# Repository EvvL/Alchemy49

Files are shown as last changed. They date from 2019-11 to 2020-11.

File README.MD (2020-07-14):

<p align="center">
   
  <br>
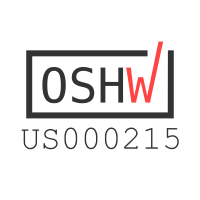
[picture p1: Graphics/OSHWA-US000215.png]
  
</p>

**Status:** Ordering final prototype

## Introduction

The Alchemy49 is a replacement pcb for the Magicforce 49 supporting south facing Switches, LEDs, PCB mounted stabilizers
and QMK. It's built around the SparkFun Pro Micro and designed to be easy to put together and solder using only one
surface mount component.

## BOM (Bill of Materials)

- 1x Promicro (or Compatible)
- 1x Micro USB Cable
- 1x XM7D-0512 MiniB (LCSC: C46398)
- 1x 6mm THT SPST Button
- 49x 1N4148 (LCSC: C14538)

If using LEDs:

- 49x 330 1/6w (LCSC: C119858)
- 49x 1.8mm LED (LCSC: C268275)
- 1x AO3402 (LCSC: C351406)
- 1x 100 1/6w (LCSC: C119846)
- 1x 10k 1/6w (LCSC: C119894)

## Layout

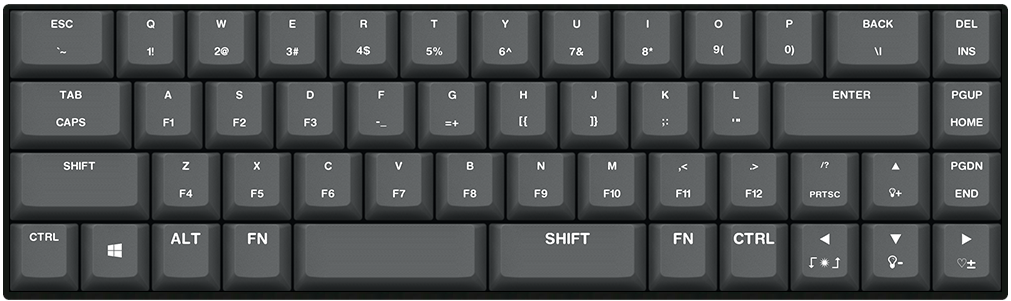
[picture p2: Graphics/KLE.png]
KLE Layout Render


Layout Render by [KLE-Render](http://kle-render.herokuapp.com/)

Click [this link](http://www.keyboard-layout-editor.com/#/gists/9abd5a1e1122fe68672f75864f8e92a3) for the KLE layout

## Firmware

For now QMK is currently supported via [KBFirmware.com](https://kbfirmware.com/). Just upload the included
[Configuration/kbfirmware.json](https://github.com/EvvL/Alchemy49/raw/master/Configuration/kbfirmware.json) into
the site, tweak the layout to your liking and compile. The resulting hex file should be flashable using
[AVRDUDESS](https://github.com/zkemble/AVRDUDESS) or [AVRDUDE](http://www.nongnu.org/avrdude/).

If you don't want to adjust anything you can use the [included prebuilt hex file](https://github.com/EvvL/Alchemy49/raw/master/Configuration/alchemy49.hex)
with all the same configuration as the stock MagicForce49 layout.

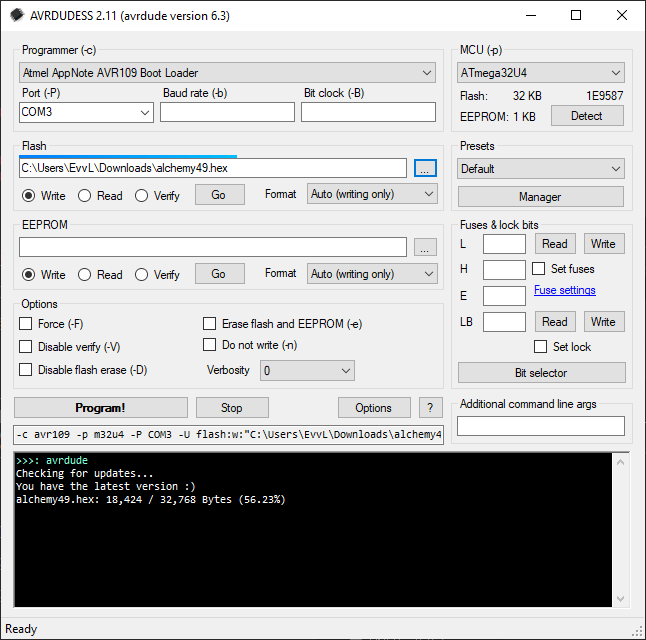
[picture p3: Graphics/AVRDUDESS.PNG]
AVRDUDESS Settings


## Renders

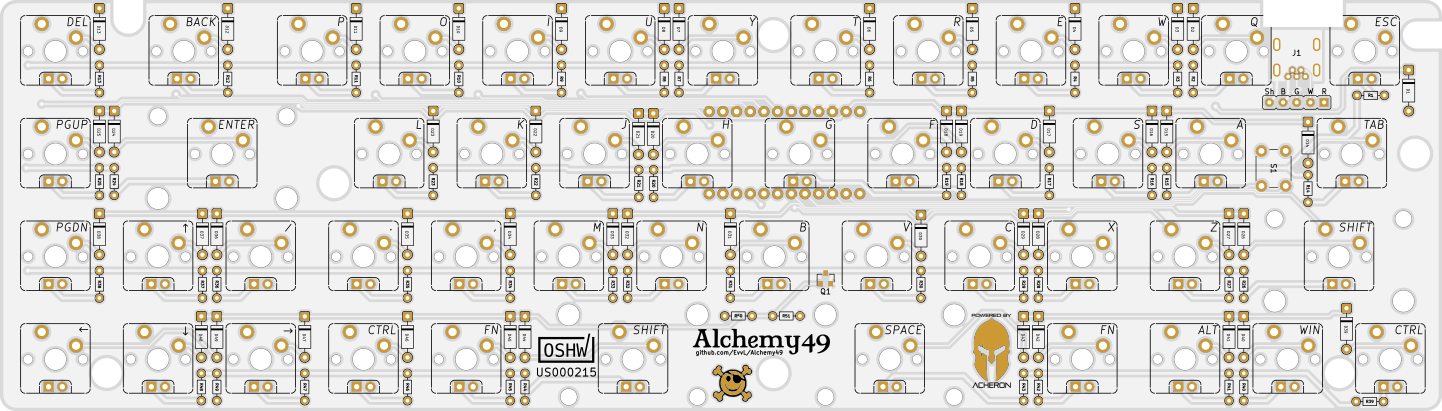
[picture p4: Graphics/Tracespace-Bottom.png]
Tracespace Render (Bottom)


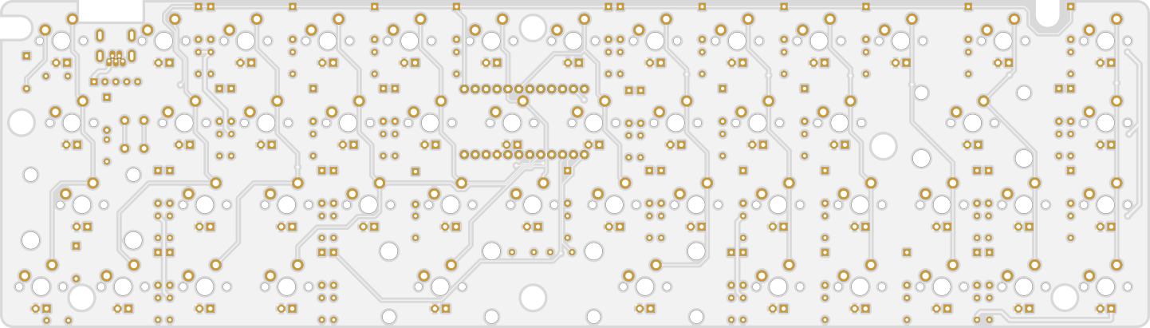
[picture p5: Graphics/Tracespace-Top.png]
Tracespace Render (Top)


PCB Renders by [Tracespace](https://tracespace.io/view/)

## Copyright and Licensing

This project is licensed under the [Acheron Open-Source Hardware License V1.2](https://github.com/EvvL/Alchemy49/blob/master/LICENSE.md)

OSHWA Certification: [US000215](https://certification.oshwa.org/us000215.html)

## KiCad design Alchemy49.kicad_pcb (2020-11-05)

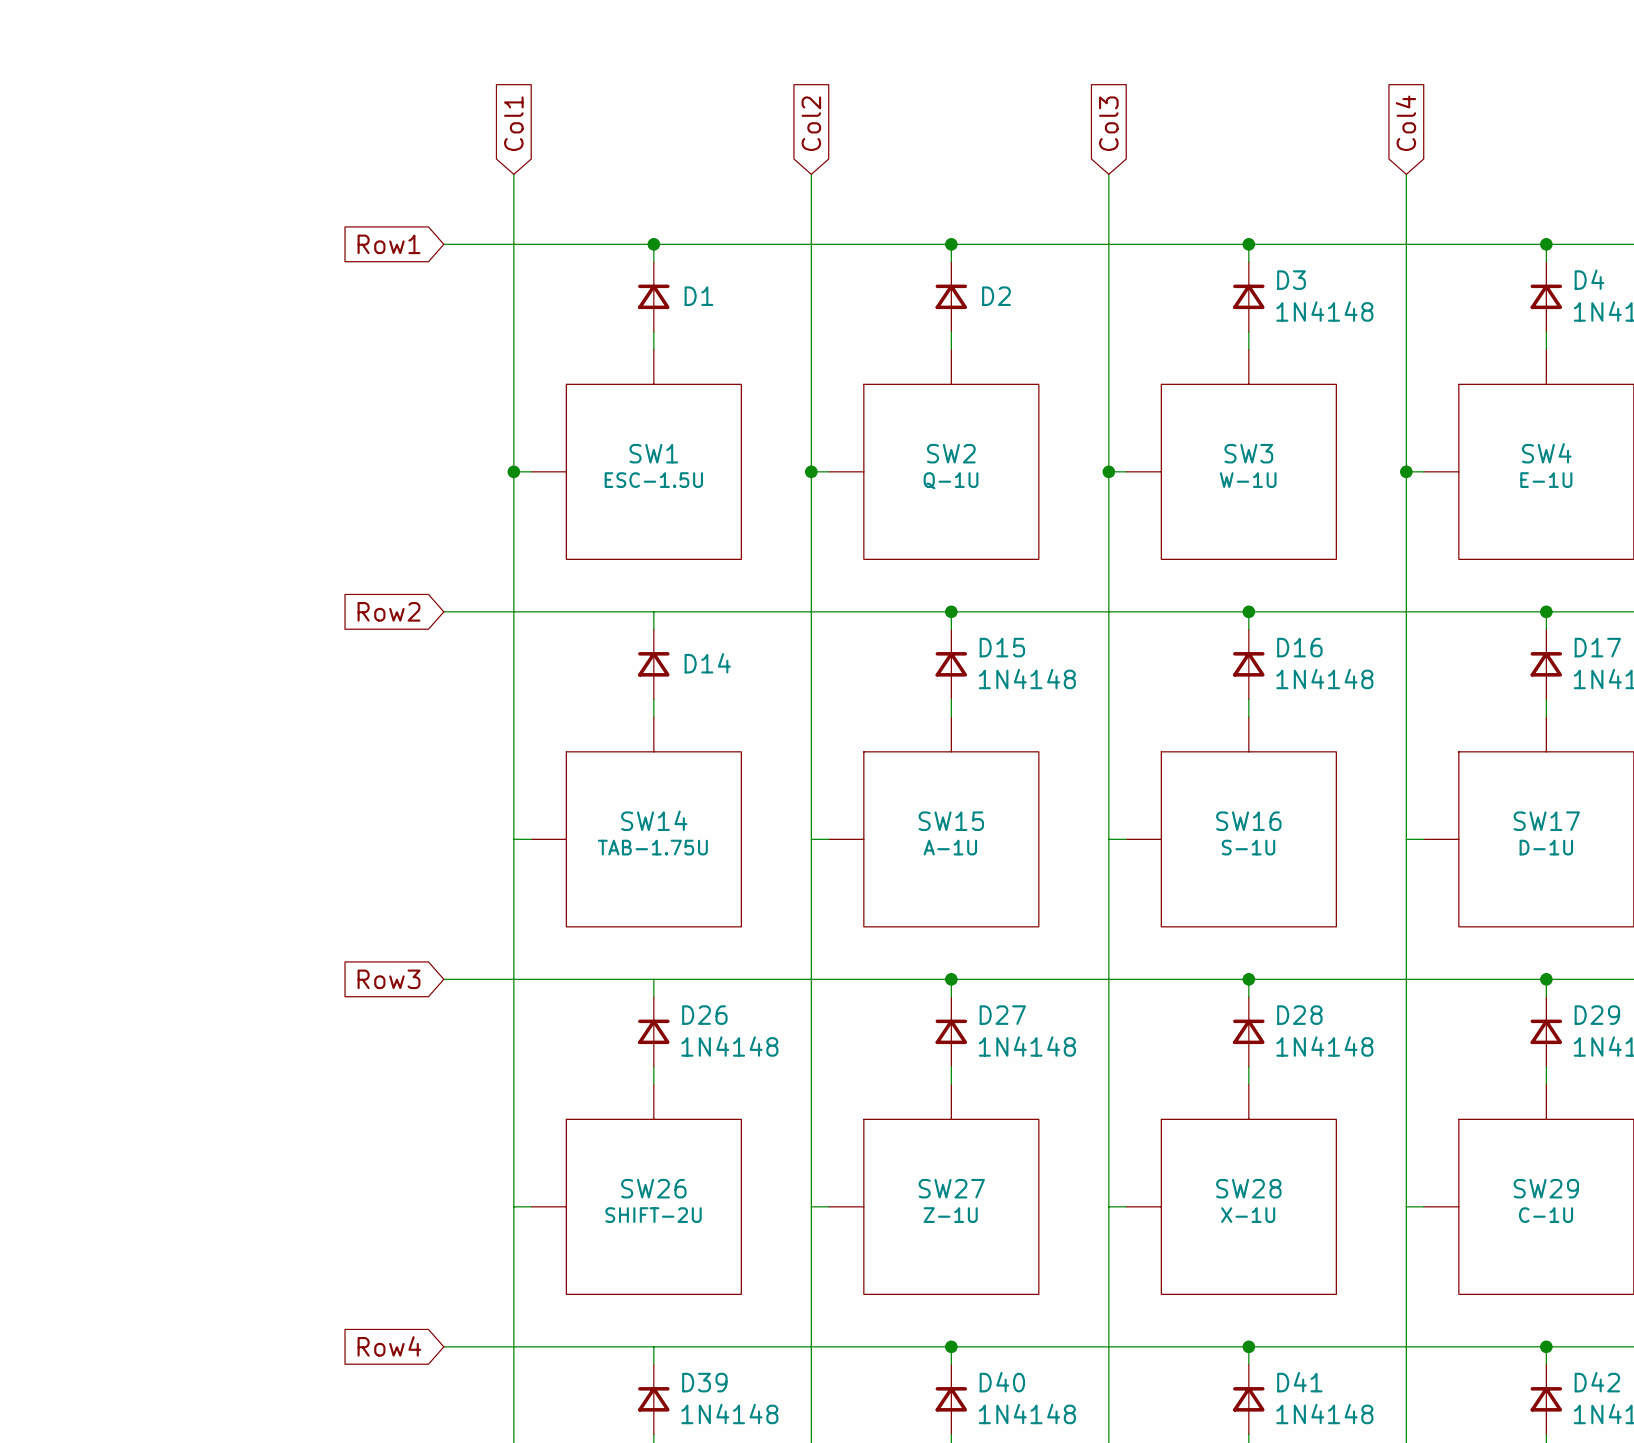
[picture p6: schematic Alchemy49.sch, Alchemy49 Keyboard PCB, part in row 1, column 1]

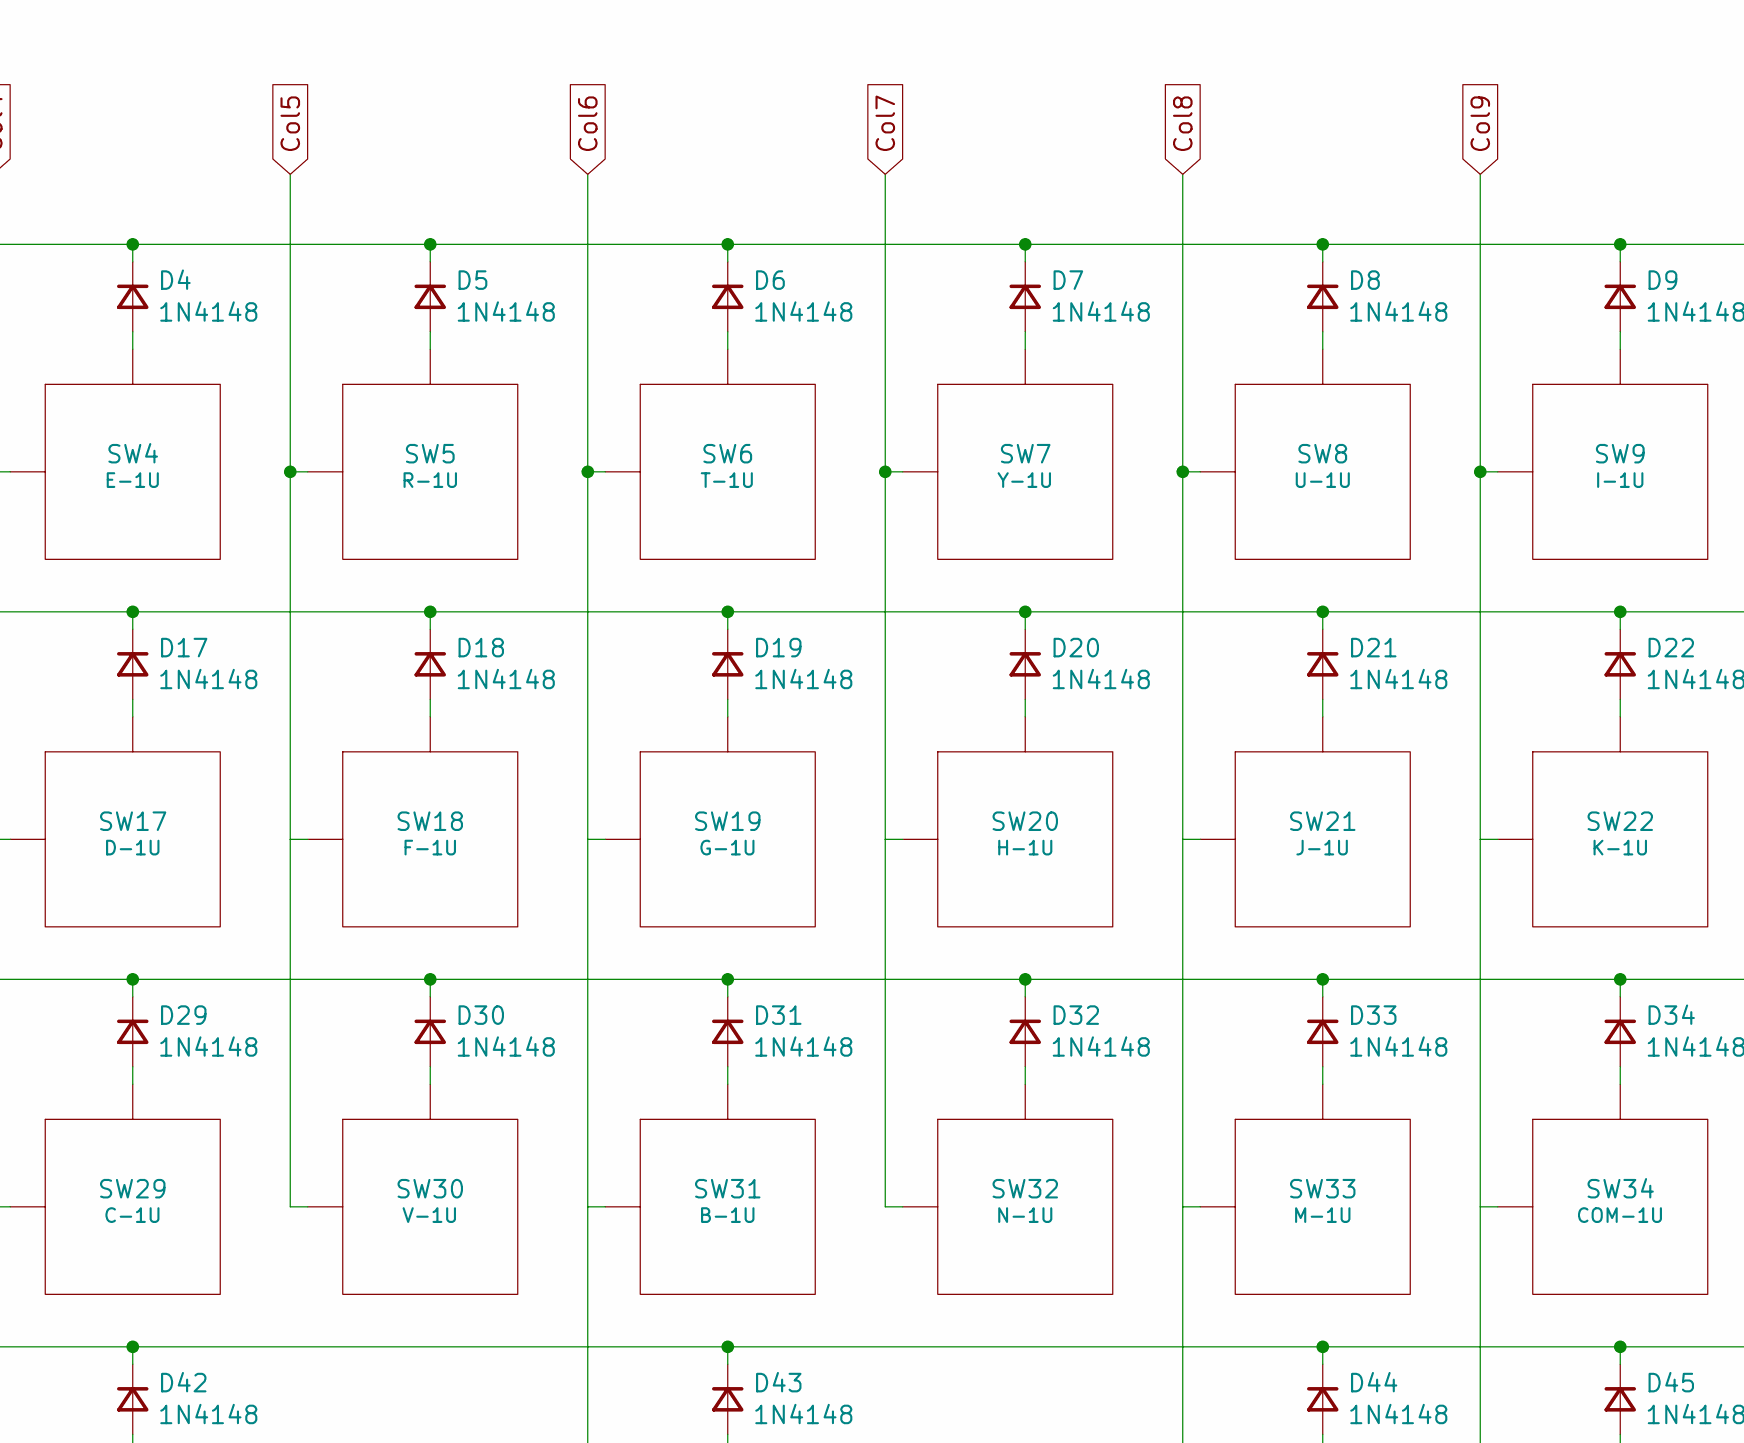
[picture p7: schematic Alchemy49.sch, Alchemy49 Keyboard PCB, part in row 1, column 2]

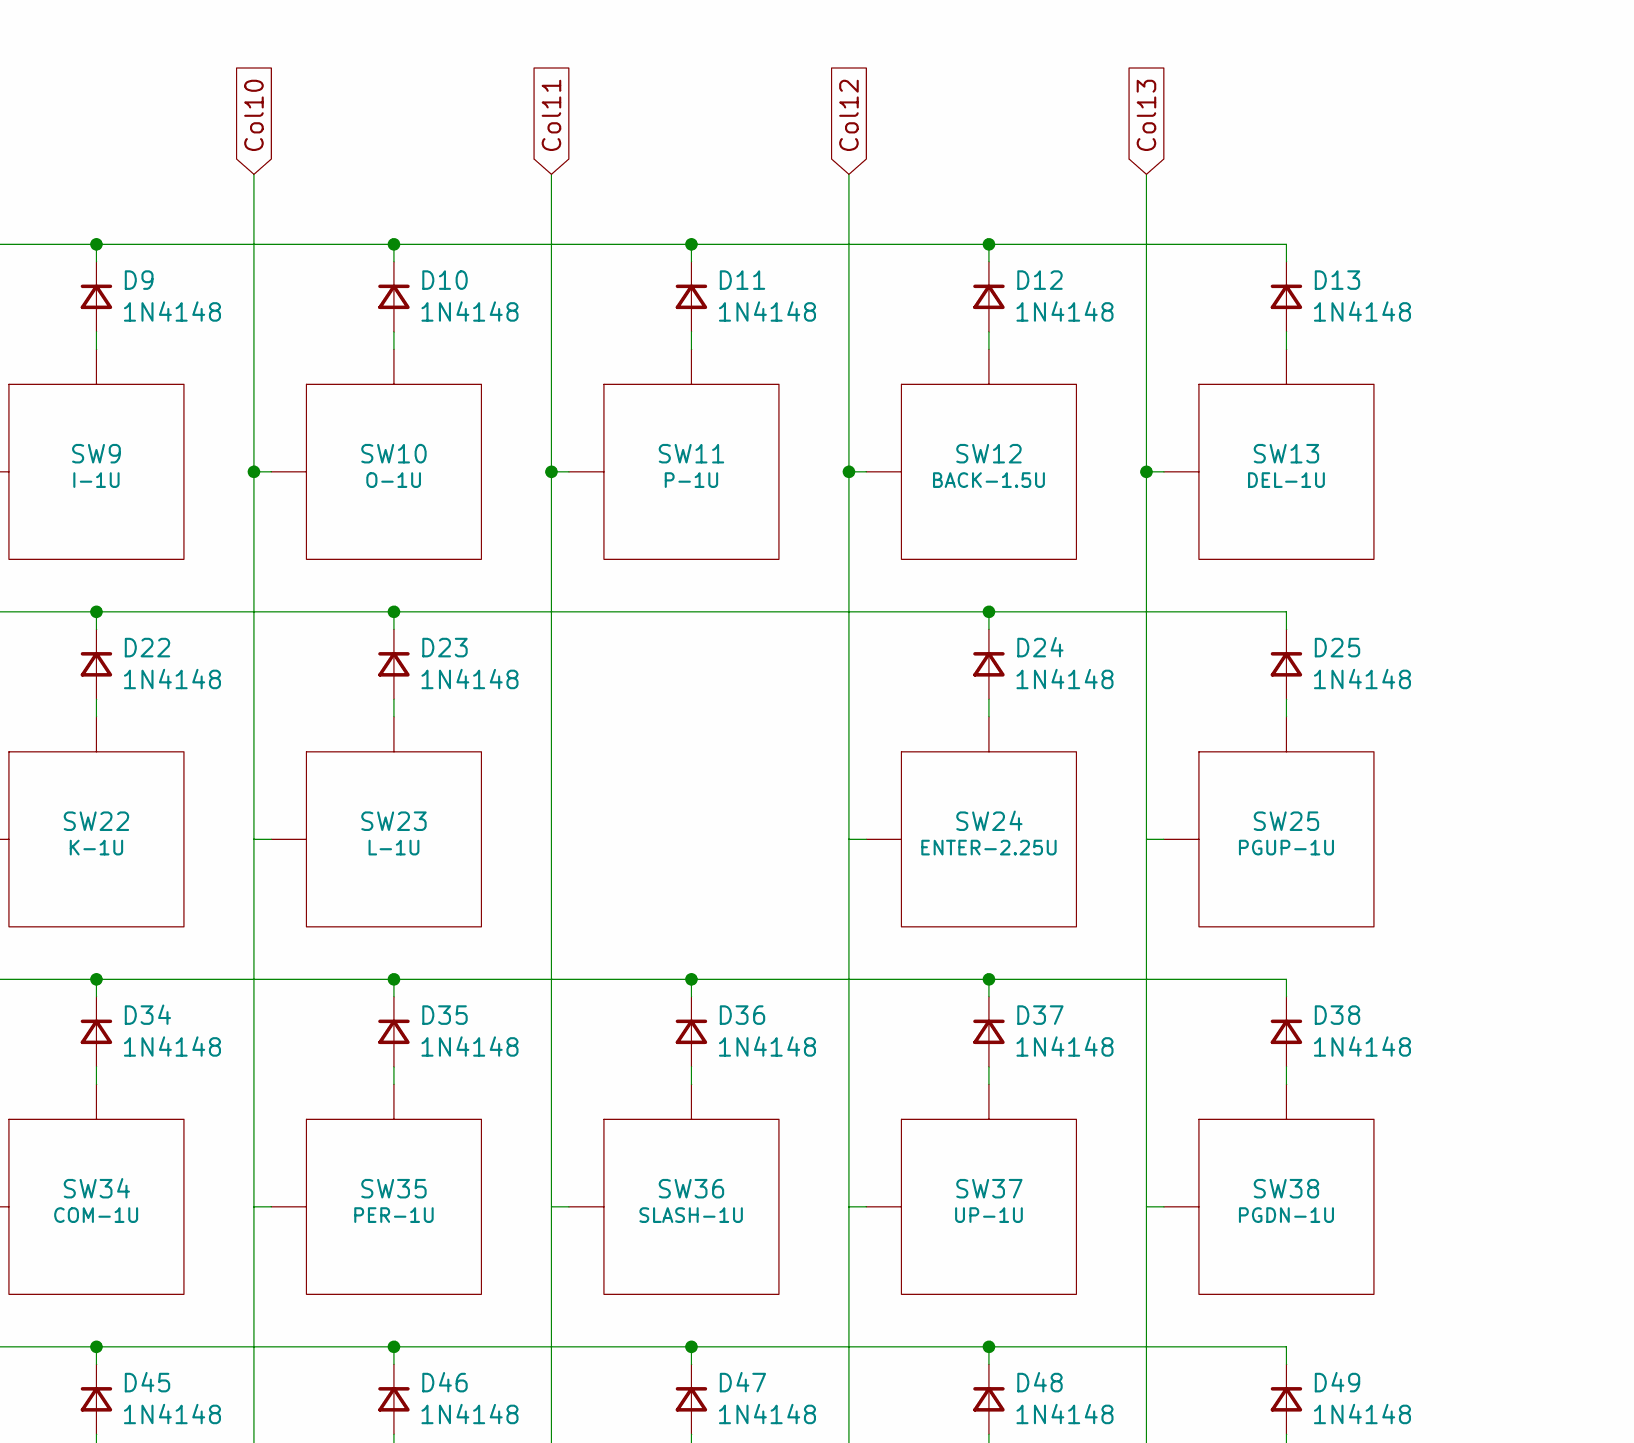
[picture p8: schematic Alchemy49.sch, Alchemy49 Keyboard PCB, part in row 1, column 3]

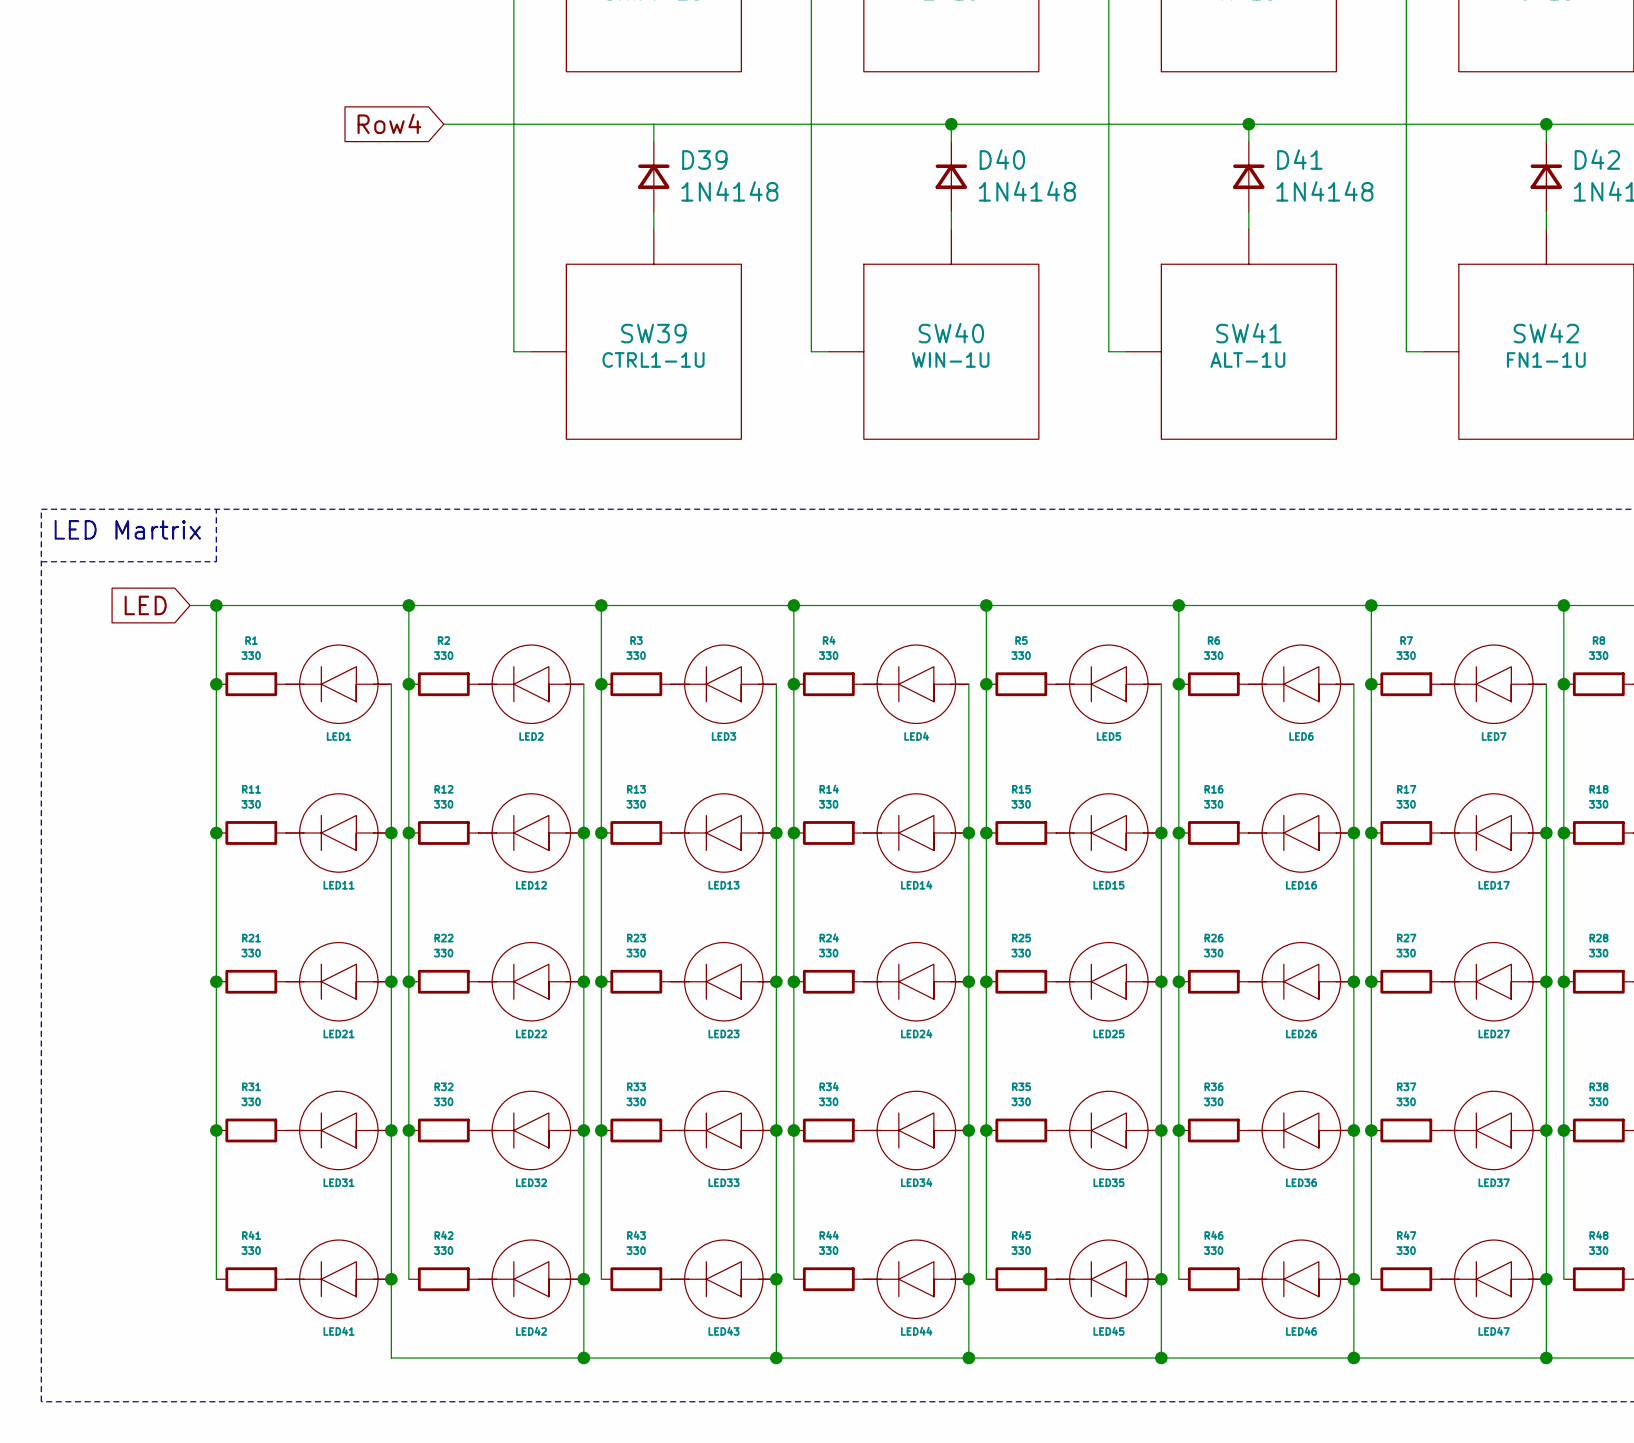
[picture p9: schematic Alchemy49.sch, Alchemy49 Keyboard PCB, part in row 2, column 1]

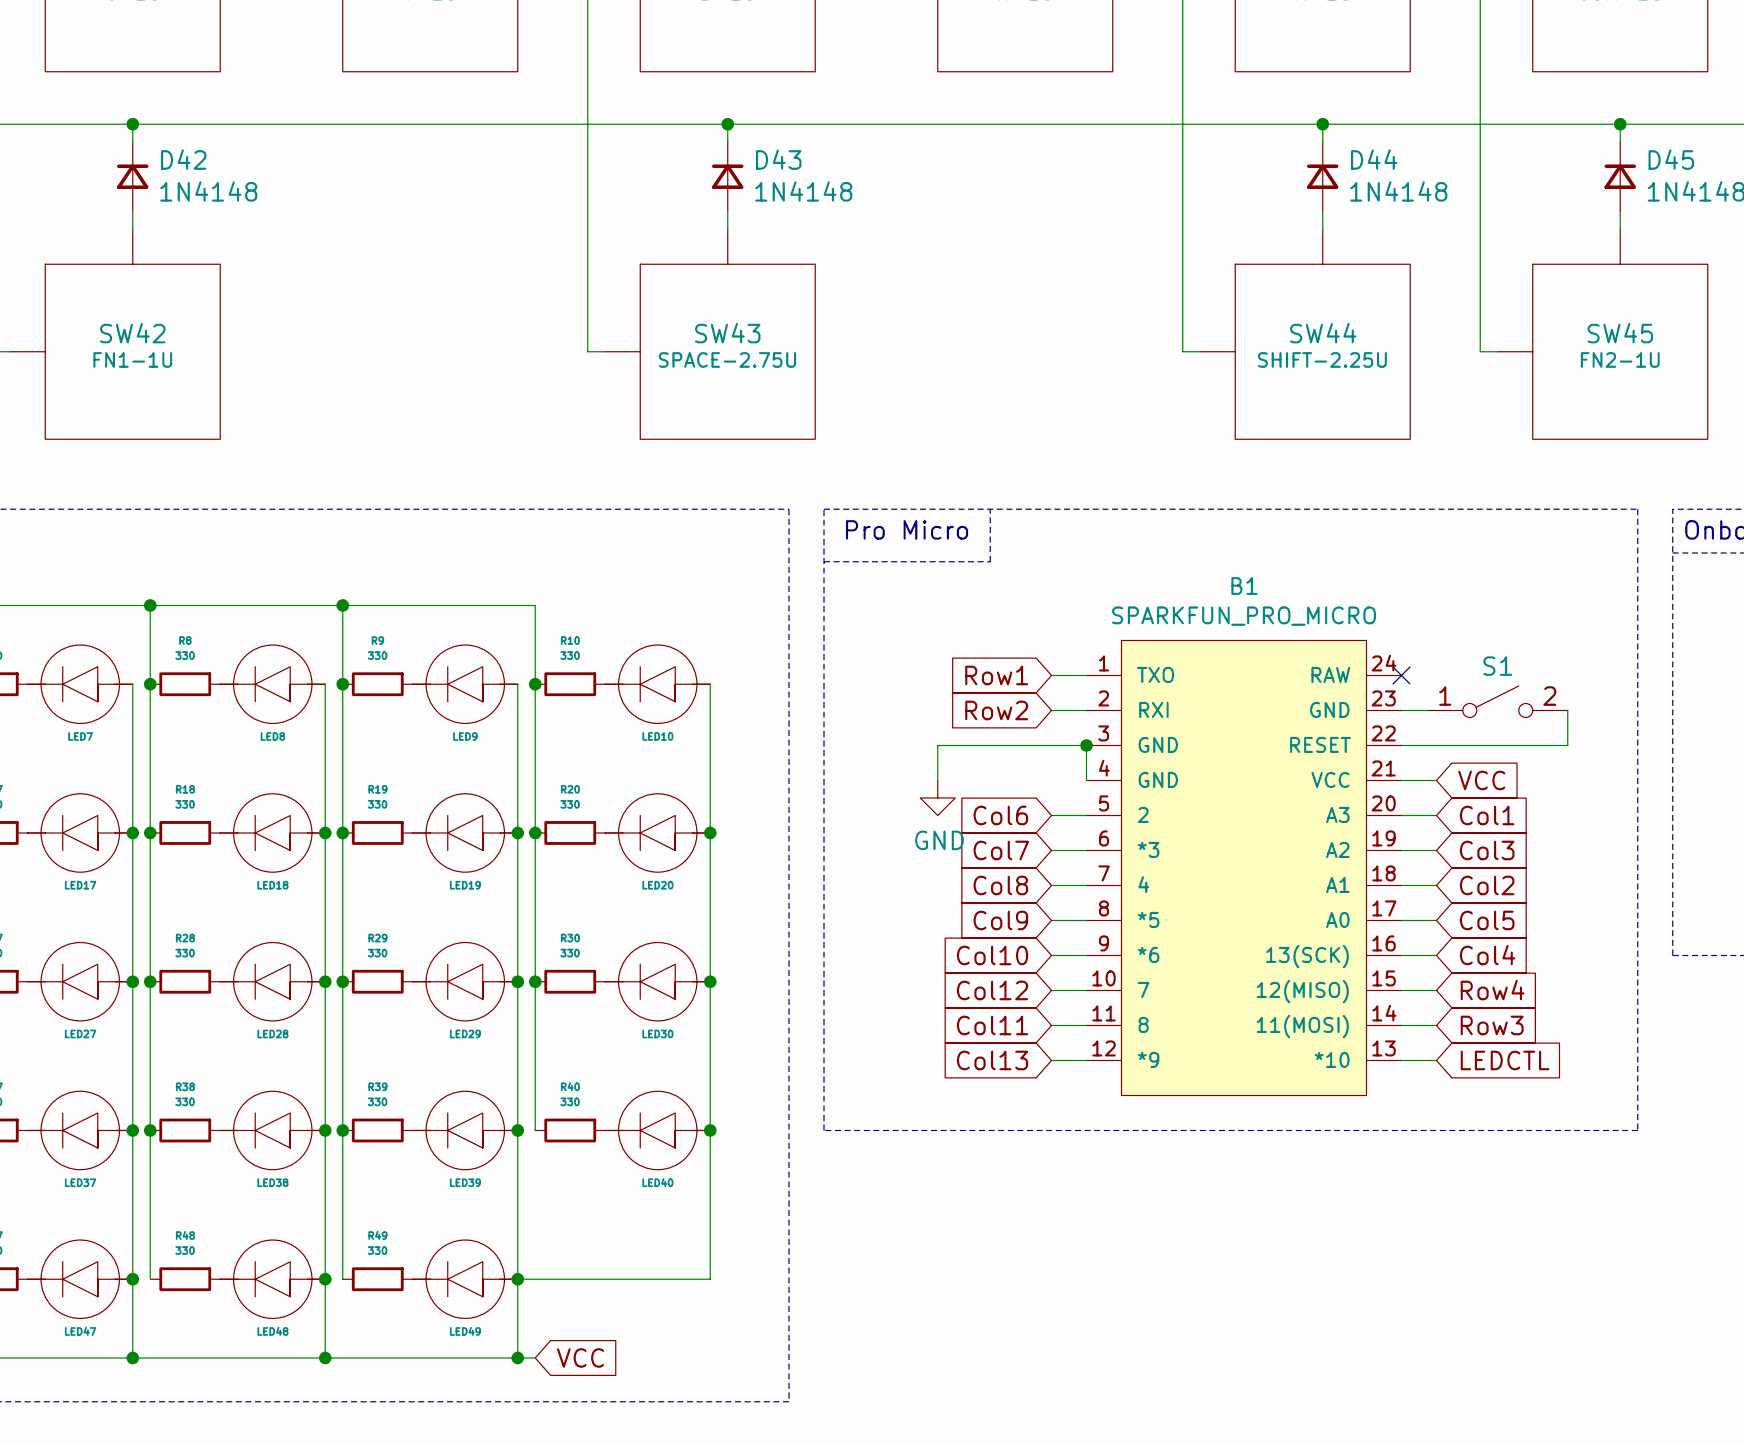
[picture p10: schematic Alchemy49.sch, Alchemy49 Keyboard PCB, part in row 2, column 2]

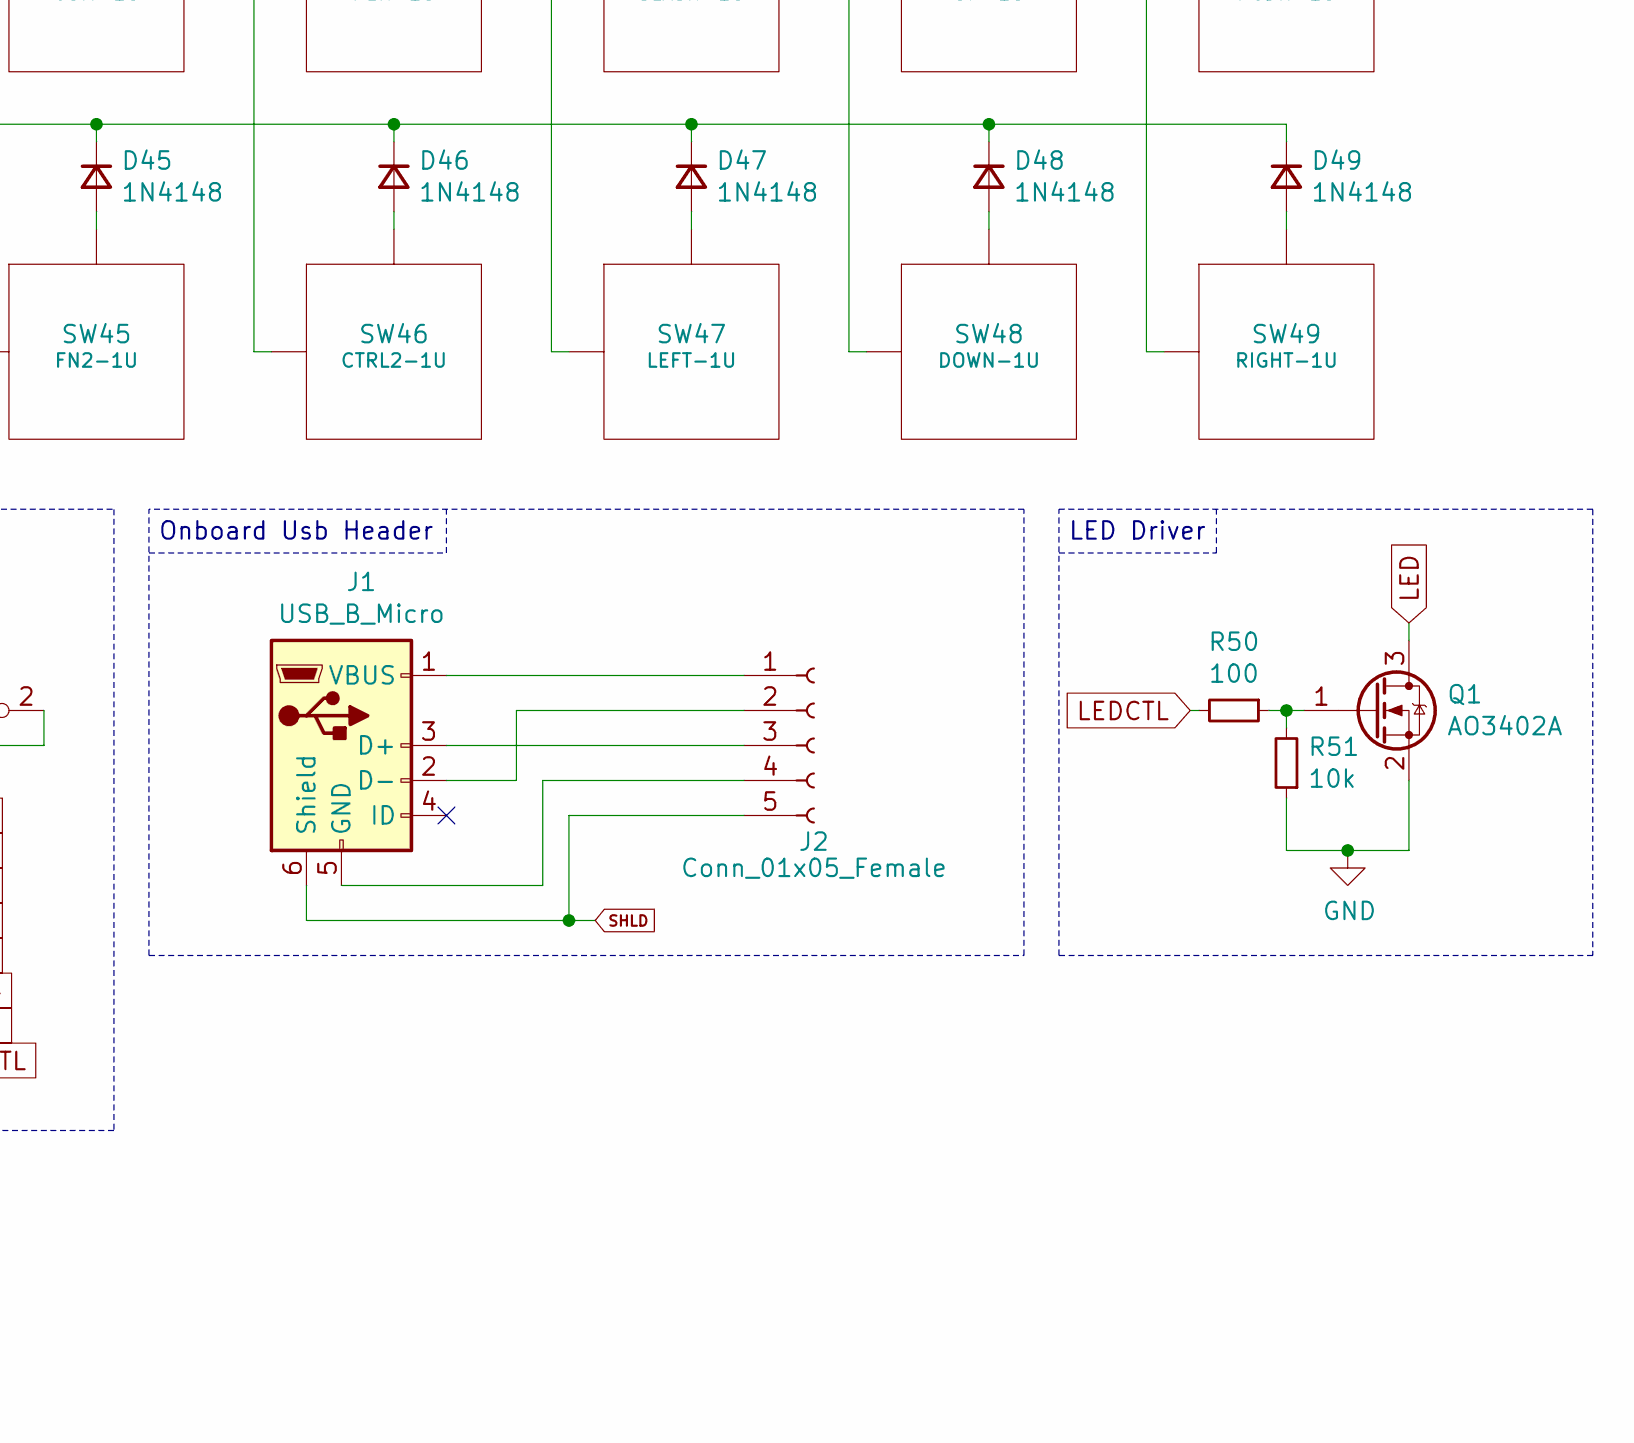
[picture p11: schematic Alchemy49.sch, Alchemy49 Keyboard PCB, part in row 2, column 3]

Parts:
B1: SPARKFUN_PRO_MICRO
D1, D2, D3, D4, D5, D6, D7, D8, D9, D10, D11, D12, D13, D14, D15, D16, D17, D18, D19, D20, D21, D22, D23, D24, D25, D26, D27, D28, D29, D30, D31, D32, D33, D34, D35, D36, D37, D38, D39, D40, D41, D42, D43, D44, D45, D46, D47, D48, D49: 1N4148; D_THT_7.62mm_SOD-123; LCSC C14538
J1: USB_B_Micro; USB_MiniB_XM7D-0512; LCSC C46398
J2: Conn_01x05_Female; PinHeader_1x5_P2.54mm_Vertical
LED1, LED2, LED3, LED4, LED5, LED6, LED7, LED8, LED9, LED10, LED11, LED12, LED13, LED14, LED15, LED16, LED17, LED18, LED19, LED20, LED21, LED22, LED23, LED24, LED25, LED26, LED27, LED28, LED29, LED30, LED31, LED32, LED33, LED34, LED35, LED36, LED37, LED38, LED39, LED40, LED41, LED42, LED43, LED44, LED45, LED46, LED47, LED48, LED49: LED; LED_THT_2.54mm; LCSC C268275
Q1: AO3402A; SOT-23; LCSC C351406
R1, R2, R3, R4, R5, R6, R7, R8, R9, R10, R11, R12, R13, R14, R15, R16, R17, R18, R19, R20, R21, R22, R23, R24, R25, R26, R27, R28, R29, R30, R31, R32, R33, R34, R35, R36, R37, R38, R39, R40, R41, R42, R43, R44, R45, R46, R47, R48, R49: 330; R_THT_5.08mm_SMD_1206; LCSC C119858
R50: 100; R_THT_5.08mm_SMD_1206; LCSC C119846
R51: 10k; R_THT_5.08mm_SMD_1206; LCSC C119894
S1: SW_SPST; SW_PUSH_6mm
SW1: ESC-1.5U; MX150
SW2: Q-1U; MX100
SW3: W-1U; MX100
SW4: E-1U; MX100
SW5: R-1U; MX100
SW6: T-1U; MX100
SW7: Y-1U; MX100
SW8: U-1U; MX100
SW9: I-1U; MX100
SW10: O-1U; MX100
SW11: P-1U; MX100
SW12: BACK-1.5U; MX150
SW13: DEL-1U; MX100
SW14: TAB-1.75U; MX175
SW15: A-1U; MX100
SW16: S-1U; MX100
SW17: D-1U; MX100
SW18: F-1U; MX100
SW19: G-1U; MX100
SW20: H-1U; MX100
SW21: J-1U; MX100
SW22: K-1U; MX100
SW23: L-1U; MX100
SW24: ENTER-2.25U; MX225
SW25: PGUP-1U; MX100
SW26: SHIFT-2U; MX200
SW27: Z-1U; MX100
SW28: X-1U; MX100
SW29: C-1U; MX100
SW30: V-1U; MX100
SW31: B-1U; MX100
SW32: N-1U; MX100
SW33: M-1U; MX100
SW34: COM-1U; MX100
SW35: PER-1U; MX100
SW36: SLASH-1U; MX100
SW37: UP-1U; MX100
SW38: PGDN-1U; MX100
SW39: CTRL1-1U; MX100
SW40: WIN-1U; MX100
SW41: ALT-1U; MX100
SW42: FN1-1U; MX100
SW43: SPACE-2.75U; MX275R
SW44: SHIFT-2.25U; MX225R
SW45: FN2-1U; MX100
SW46: CTRL2-1U; MX100
SW47: LEFT-1U; MX100
SW48: DOWN-1U; MX100
SW49: RIGHT-1U; MX100

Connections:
Col1: B1.20 (A3), SW1.1 (Col), SW14.1 (Col), SW26.1 (Col), SW39.1 (Col)
Col2: B1.18 (A1), SW2.1 (Col), SW15.1 (Col), SW27.1 (Col), SW40.1 (Col)
Col3: B1.19 (A2), SW3.1 (Col), SW16.1 (Col), SW28.1 (Col), SW41.1 (Col)
Col4: B1.16 (13(SCK)), SW4.1 (Col), SW17.1 (Col), SW29.1 (Col), SW42.1 (Col)
Col5: B1.17 (A0), SW5.1 (Col), SW18.1 (Col), SW30.1 (Col)
Col6: B1.5 (2), SW6.1 (Col), SW19.1 (Col), SW31.1 (Col), SW43.1 (Col)
Col7: B1.6 (*3), SW7.1 (Col), SW20.1 (Col), SW32.1 (Col)
Col8: B1.7 (4), SW8.1 (Col), SW21.1 (Col), SW33.1 (Col), SW44.1 (Col)
Col9: B1.8 (*5), SW9.1 (Col), SW22.1 (Col), SW34.1 (Col), SW45.1 (Col)
Col10: B1.9 (*6), SW10.1 (Col), SW23.1 (Col), SW35.1 (Col), SW46.1 (Col)
Col11: B1.11 (8), SW11.1 (Col), SW36.1 (Col), SW47.1 (Col)
Col12: B1.10 (7), SW12.1 (Col), SW24.1 (Col), SW37.1 (Col), SW48.1 (Col)
Col13: B1.12 (*9), SW13.1 (Col), SW25.1 (Col), SW38.1 (Col), SW49.1 (Col)
GND: B1.3 (GND), B1.4 (GND), Q1.2 (S), R51.1
LED: Q1.3 (D), R1.2, R2.2, R3.2, R4.2, R5.2, R6.2, R7.2, R8.2, R9.2, R10.2, R11.2, R12.2, R13.2, R14.2, R15.2, R16.2, R17.2, R18.2, R19.2, R20.2, R21.2, R22.2, R23.2, R24.2, R25.2, R26.2, R27.2, R28.2, R29.2, R30.2, R31.2, R32.2, R33.2, R34.2, R35.2, R36.2, R37.2, R38.2, R39.2, R40.2, R41.2, R42.2, R43.2, R44.2, R45.2, R46.2, R47.2, R48.2, R49.2
LEDCTL: B1.13 (*10), R50.2
unnamed: B1.22 (RESET), S1.2 (B)
unnamed: B1.23 (GND), S1.1 (A)
unnamed: D1.2 (A), SW1.2 (Row)
unnamed: D2.2 (A), SW2.2 (Row)
unnamed: D3.2 (A), SW3.2 (Row)
unnamed: D4.2 (A), SW4.2 (Row)
unnamed: D5.2 (A), SW5.2 (Row)
unnamed: D6.2 (A), SW6.2 (Row)
unnamed: D7.2 (A), SW7.2 (Row)
unnamed: D8.2 (A), SW8.2 (Row)
unnamed: D9.2 (A), SW9.2 (Row)
unnamed: D10.2 (A), SW10.2 (Row)
unnamed: D11.2 (A), SW11.2 (Row)
unnamed: D12.2 (A), SW12.2 (Row)
unnamed: D13.2 (A), SW13.2 (Row)
unnamed: D14.2 (A), SW14.2 (Row)
unnamed: D15.2 (A), SW15.2 (Row)
unnamed: D16.2 (A), SW16.2 (Row)
unnamed: D17.2 (A), SW17.2 (Row)
unnamed: D18.2 (A), SW18.2 (Row)
unnamed: D19.2 (A), SW19.2 (Row)
unnamed: D20.2 (A), SW20.2 (Row)
unnamed: D21.2 (A), SW21.2 (Row)
unnamed: D22.2 (A), SW22.2 (Row)
unnamed: D23.2 (A), SW23.2 (Row)
unnamed: D24.2 (A), SW24.2 (Row)
unnamed: D25.2 (A), SW25.2 (Row)
unnamed: D26.2 (A), SW26.2 (Row)
unnamed: D27.2 (A), SW27.2 (Row)
unnamed: D28.2 (A), SW28.2 (Row)
unnamed: D29.2 (A), SW29.2 (Row)
unnamed: D30.2 (A), SW30.2 (Row)
unnamed: D31.2 (A), SW31.2 (Row)
unnamed: D32.2 (A), SW32.2 (Row)
unnamed: D33.2 (A), SW33.2 (Row)
unnamed: D34.2 (A), SW34.2 (Row)
unnamed: D35.2 (A), SW35.2 (Row)
unnamed: D36.2 (A), SW36.2 (Row)
unnamed: D37.2 (A), SW37.2 (Row)
unnamed: D38.2 (A), SW38.2 (Row)
unnamed: D39.2 (A), SW39.2 (Row)
unnamed: D40.2 (A), SW40.2 (Row)
unnamed: D41.2 (A), SW41.2 (Row)
unnamed: D42.2 (A), SW42.2 (Row)
unnamed: D43.2 (A), SW43.2 (Row)
unnamed: D44.2 (A), SW44.2 (Row)
unnamed: D45.2 (A), SW45.2 (Row)
unnamed: D46.2 (A), SW46.2 (Row)
unnamed: D47.2 (A), SW47.2 (Row)
unnamed: D48.2 (A), SW48.2 (Row)
unnamed: D49.2 (A), SW49.2 (Row)
unnamed: J1.1 (VBUS), J2.1
unnamed: J1.2 (D-), J2.2
unnamed: J1.3 (D+), J2.3
unnamed: J1.5 (GND), J2.4
unnamed: LED1.K, R1.1
unnamed: LED2.K, R2.1
unnamed: LED3.K, R3.1
unnamed: LED4.K, R4.1
unnamed: LED5.K, R5.1
unnamed: LED6.K, R6.1
unnamed: LED7.K, R7.1
unnamed: LED8.K, R8.1
unnamed: LED9.K, R9.1
unnamed: LED10.K, R10.1
unnamed: LED11.K, R11.1
unnamed: LED12.K, R12.1
unnamed: LED13.K, R13.1
unnamed: LED14.K, R14.1
unnamed: LED15.K, R15.1
unnamed: LED16.K, R16.1
unnamed: LED17.K, R17.1
unnamed: LED18.K, R18.1
unnamed: LED19.K, R19.1
unnamed: LED20.K, R20.1
unnamed: LED21.K, R21.1
unnamed: LED22.K, R22.1
unnamed: LED23.K, R23.1
unnamed: LED24.K, R24.1
unnamed: LED25.K, R25.1
unnamed: LED26.K, R26.1
unnamed: LED27.K, R27.1
unnamed: LED28.K, R28.1
unnamed: LED29.K, R29.1
unnamed: LED30.K, R30.1
unnamed: LED31.K, R31.1
unnamed: LED32.K, R32.1
unnamed: LED33.K, R33.1
unnamed: LED34.K, R34.1
unnamed: LED35.K, R35.1
unnamed: LED36.K, R36.1
unnamed: LED37.K, R37.1
unnamed: LED38.K, R38.1
unnamed: LED39.K, R39.1
unnamed: LED40.K, R40.1
unnamed: LED41.K, R41.1
unnamed: LED42.K, R42.1
unnamed: LED43.K, R43.1
unnamed: LED44.K, R44.1
unnamed: LED45.K, R45.1
unnamed: LED46.K, R46.1
unnamed: LED47.K, R47.1
unnamed: LED48.K, R48.1
unnamed: LED49.K, R49.1
unnamed: Q1.1 (G), R50.1, R51.2
Row1: B1.1 (TXO), D1.1 (K), D2.1 (K), D3.1 (K), D4.1 (K), D5.1 (K), D6.1 (K), D7.1 (K), D8.1 (K), D9.1 (K), D10.1 (K), D11.1 (K), D12.1 (K), D13.1 (K)
Row2: B1.2 (RXI), D14.1 (K), D15.1 (K), D16.1 (K), D17.1 (K), D18.1 (K), D19.1 (K), D20.1 (K), D21.1 (K), D22.1 (K), D23.1 (K), D24.1 (K), D25.1 (K)
Row3: B1.14 (11(MOSI)), D26.1 (K), D27.1 (K), D28.1 (K), D29.1 (K), D30.1 (K), D31.1 (K), D32.1 (K), D33.1 (K), D34.1 (K), D35.1 (K), D36.1 (K), D37.1 (K), D38.1 (K)
Row4: B1.15 (12(MISO)), D39.1 (K), D40.1 (K), D41.1 (K), D42.1 (K), D43.1 (K), D44.1 (K), D45.1 (K), D46.1 (K), D47.1 (K), D48.1 (K), D49.1 (K)
SHLD: J1.6 (Shield), J2.5
VCC: B1.21 (VCC), LED1.A, LED2.A, LED3.A, LED4.A, LED5.A, LED6.A, LED7.A, LED8.A, LED9.A, LED10.A, LED11.A, LED12.A, LED13.A, LED14.A, LED15.A, LED16.A, LED17.A, LED18.A, LED19.A, LED20.A, LED21.A, LED22.A, LED23.A, LED24.A, LED25.A, LED26.A, LED27.A, LED28.A, LED29.A, LED30.A, LED31.A, LED32.A, LED33.A, LED34.A, LED35.A, LED36.A, LED37.A, LED38.A, LED39.A, LED40.A, LED41.A, LED42.A, LED43.A, LED44.A, LED45.A, LED46.A, LED47.A, LED48.A, LED49.A

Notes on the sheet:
Onboard Usb Header
Pro Micro
LED Martrix
LED Driver

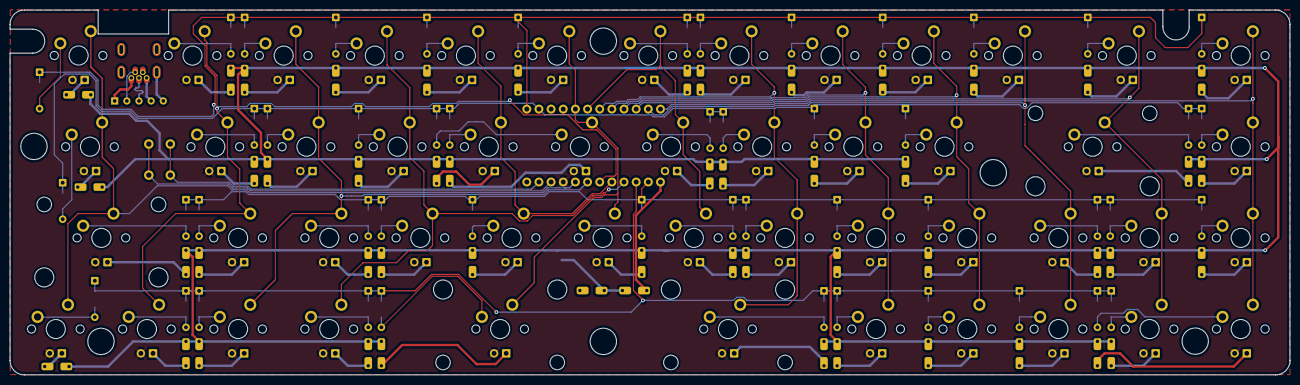
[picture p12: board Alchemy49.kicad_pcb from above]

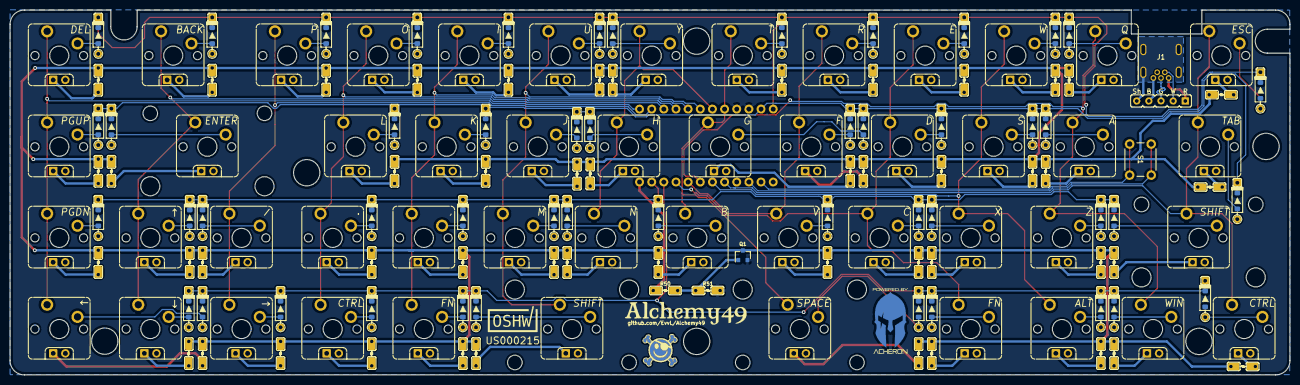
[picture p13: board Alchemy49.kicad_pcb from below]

Board: 2 copper layers, 267.5 x 76.2 mm, 253 parts (204 on the bottom side), 127 nets.

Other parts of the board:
,: Switch SilkS
.: Switch SilkS
/: Switch SilkS
A: Switch SilkS
ALT: Switch SilkS
B: Switch SilkS
BACK: Switch SilkS
C: Switch SilkS
CTRL: Switch SilkS
CTRL#2: Switch SilkS
D: Switch SilkS
DEL: Switch SilkS
E: Switch SilkS
ENTER: Switch SilkS
ESC: Switch SilkS
F: Switch SilkS
FN: Switch SilkS
FN#2: Switch SilkS
G: Switch SilkS
H: Switch SilkS
I: Switch SilkS
J: Switch SilkS
K: Switch SilkS
L: Switch SilkS
M: Switch SilkS
N: Switch SilkS
O: Switch SilkS
OSHW_Mono_0.25_Scale: US000215; OSHW_Mono_0.25_Scale
P: Switch SilkS
PGDN: Switch SilkS
PGUP: Switch SilkS
Q: Switch SilkS
R: Switch SilkS
S: Switch SilkS
SHIFT: Switch SilkS
SHIFT#2: Switch SilkS
SPACE: Switch SilkS
T: Switch SilkS
TAB: Switch SilkS
U: Switch SilkS
V: Switch SilkS
W: Switch SilkS
WIN: Switch SilkS
X: Switch SilkS
Y: Switch SilkS
Z: Switch SilkS
←: Switch SilkS
↑: Switch SilkS
→: Switch SilkS
↓: Switch SilkS

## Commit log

2019-11-25 Inital Release
    [Alchemy49-B_Cu.gbr, Alchemy49-B_Mask.gbr, Alchemy49-B_Paste.gbr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]
2019-11-25 Rerouted the USB data lines
    [Alchemy49-B_Cu.gbr, Alchemy49-B_Mask.gbr, Alchemy49-B_Paste.gbr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]
2019-11-27 Updated to new XM7D footprint in the Acheron Library
    [Alchemy49-B_Cu.gbr, Alchemy49-B_Mask.gbr, Alchemy49-B_Paste.gbr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]
2019-11-27 Updated Acheron Library
    [Alchemy49-B_Cu.gbr, Alchemy49-B_Mask.gbr, Alchemy49-B_Paste.gbr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]
2019-12-11 Added Switch Silkscreen Outlines
    [Alchemy49.kicad_pcb]
2019-12-11 Adjusted MOSFET location
    [Alchemy49.kicad_pcb]
2019-12-13 Added Bottom Silk Screen
    [Alchemy49-B_Cu.gbr, Alchemy49-B_Mask.gbr, Alchemy49-B_Paste.gbr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]
2020-01-02 Finalized Board Design
    [Alchemy49-B_Cu.gbr, Alchemy49-B_Mask.gbr, Alchemy49-B_SilkS.gbr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]
2020-01-04 Updated led traces
    [Alchemy49-B_Cu.gbr, Alchemy49-B_Mask.gbr, Alchemy49-B_SilkS.gbr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]
2020-01-06 Prototypes Ordered
    [Alchemy49-B_Cu.gbr, Alchemy49-B_Mask.gbr, Alchemy49-B_SilkS.gbr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]
2020-01-12 First set of minor size adjustments
    Updated some of the edge cuts for a better fit, updated the board renders to match what the prototypes are
    [Alchemy49-B_Cu.gbr, Alchemy49-B_Mask.gbr, Alchemy49-B_SilkS.gbr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]
2020-01-21 Prototype Adjustments
    * Added working KBFirmware config and hex files.
    * Added example AVRDUDESS screenshot
    * Added datasheet and part numbers to sch
    * Adjusted pcb outlin and holes
    [Alchemy49.kicad_pcb, Alchemy49.sch]
2020-01-25 Cut layer adjustments for final
    [Alchemy49.kicad_pcb]
2020-01-27 OSHWA Certification
    [Alchemy49.kicad_pcb]
2020-01-27 EvvL Logo
    [Alchemy49.kicad_pcb]
2020-02-20 Changed MOSFET to FDS6630A
    [Alchemy49.kicad_pcb, Alchemy49.sch]
2020-03-16 flipped the leds around the correct way
    [Alchemy49.kicad_pcb, Alchemy49.sch]
2020-05-26 Changed MOSFET to AO3402, Removed 3D models from display
    [Alchemy49.kicad_pcb, Alchemy49.sch]
2020-07-14 New Graphics
    Added newest gerbers and graphics. Also added LCSC field to sch
    [Alchemy49-B_Cu.gbr, Alchemy49-B_Mask.gbr, Alchemy49-B_SilkS.gbr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]
2020-11-03 Changed to combination THT and surfacemount for the diodes
    [Alchemy49-B_Cu-RIN.gbr, Alchemy49-B_Mask-RIN.gbr, Alchemy49-B_SilkS-RIN.gbr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]
2020-11-04 Added new combined THT and 1206 footprint for the resistors
    [Alchemy49.kicad_pcb]
2020-11-05 reworked new footprint and fixed issues
    [Alchemy49.kicad_pcb]
